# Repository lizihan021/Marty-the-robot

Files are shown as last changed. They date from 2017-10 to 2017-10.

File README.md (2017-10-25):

---
title: DIY Marty the Robot
tags: 
- RaspberryPi
author: Li Zihan 
---

**Abstract**
---

**Marty the Robot** is a robot designed and manufactured by myself. To be honest I made the robot for fun. However, the robot could be used for teaching children programing. 

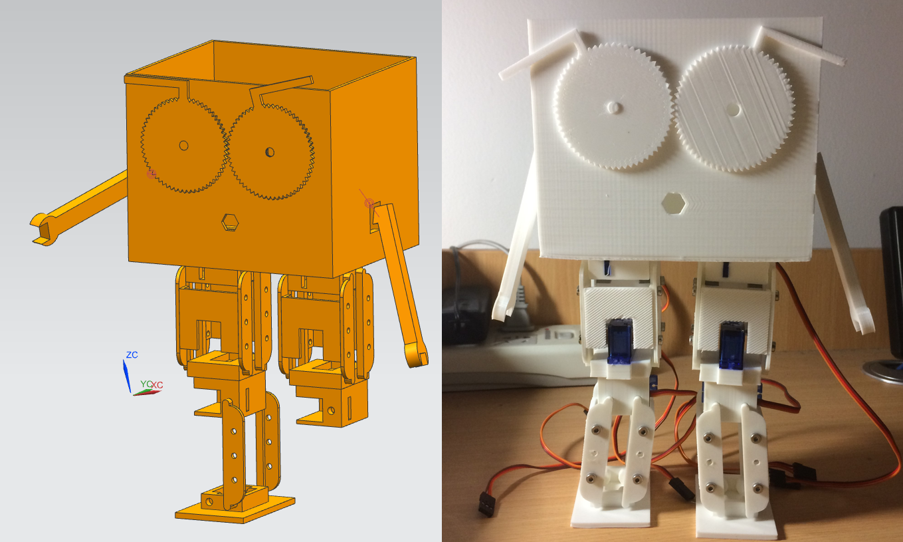
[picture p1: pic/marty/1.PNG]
marty


I used [Siemens NX](https://en.wikipedia.org/wiki/Siemens_NX) for CAD and 3D printed all the parts. Control system was based on Raspberry Pi and PCA9685 with I2C protocol. Marty was able to perform face detection with OpenCV and walk towards its owner. High level API was implemented for controlling the robot such as `walk(),dance()` etc. 

<!-- more -->

## **System Implementation**
### **1. Setup**
#### **Hardware:**
* 8mm*M3 screws 
* a 3D printer with plenty of PLA
* SG90 Servo *9
* PCA9685 module
* Raspberry Pi 3 B+
* Pi Camera
* 500 mAh, 11.1 V Li-battery
* voltage reduction module 11.1 V to 6 V

#### **Software:**
1. When you buy a raspberrypi, it's just a bare board without any operating system. Let's assume you have already installed latest Raspbian OS on your raspberrypi and and have succesfully remote control your pi. If you haven't yet finished, please follow the instruction below to **initialize your raspberrypi**:
   http://yesyzq.github.io/2016/01/09/raspberry/
   Make sure that you have network environment for raspberry pi to work properly.

2. In case you are not familiar with **Linux command**:
   http://yesyzq.github.io/2016/01/17/Linux%E5%91%BD%E4%BB%A4%E4%BB%A5%E5%8F%8A%E5%BF%AB%E6%8D%B7%E9%94%AE%E6%95%B4%E7%90%86/
   You may also refer to any other guide online. There are always abundant resources waiting for you to explore on the internet.

### **2. Implementation:**
#### **Hardware:**
I 3D printed all the parts that are needed to build Marty. The parts are designed using UG NX 10.0 and are exported to .stl files. Then those .stl files are used to generate .gcode or .pcode using slicing softwares. 
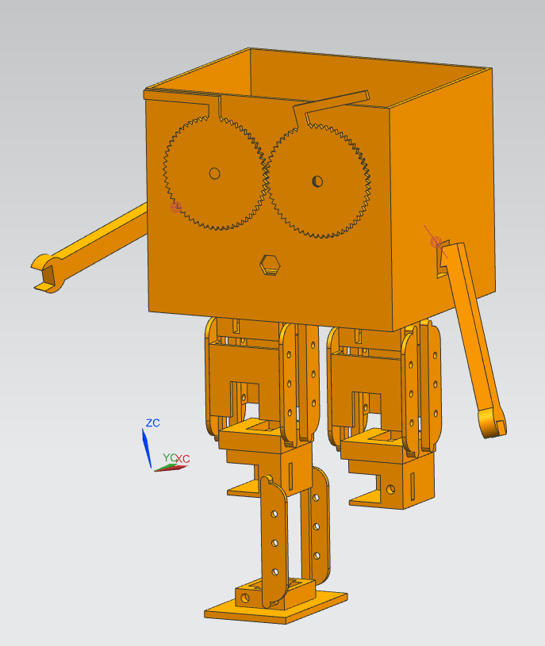
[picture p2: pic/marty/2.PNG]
Assemble the parts in UG

That is what marty is going to look like. (I'm too lazy to assemble another leg ...)
The following are all the files:
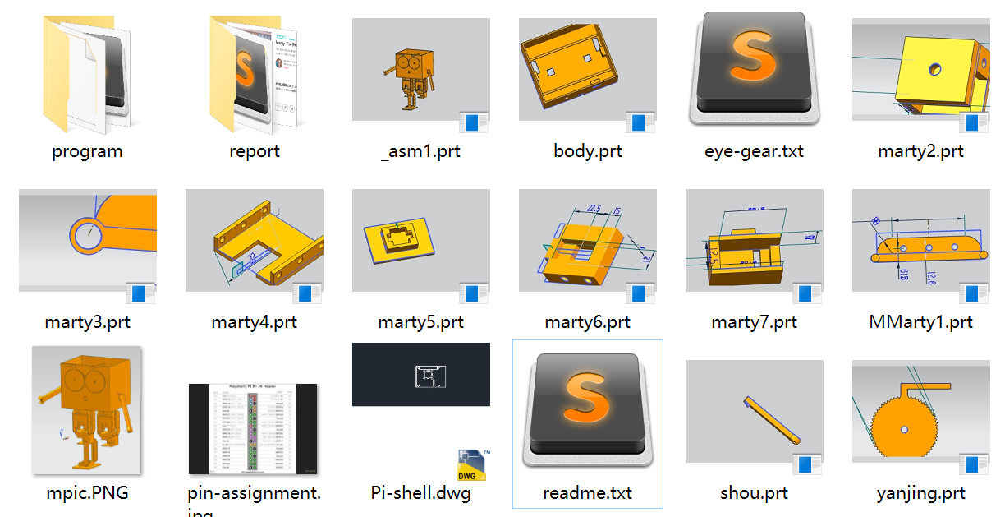
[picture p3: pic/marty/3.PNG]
all the .prt files

You need to export *.prt files to *.stl files for 3D printing.
You need to print:

* 12 pieces of MMarty1.prt - connecting bar
* 8 pieces of marty4.prt ----- supporting plate
* 4 pieces of marty3.prt ----- servo connecting bar
* 2 pieces of marty2.prt ----- third servo
* 2 pieces of marty5.prt ----- feet of marty
* 2 pieces of marty6.prt ----- second servo
* 2 pieces of marty7.prt ----- first servo
* 2 pieces of shou.prt ------- arms of marty
* 2 pieces of yanjing.prt ---- eyes of marty
* 1 piece of body.prt --------- body of marty

Then with the parts, you can assemble marty:
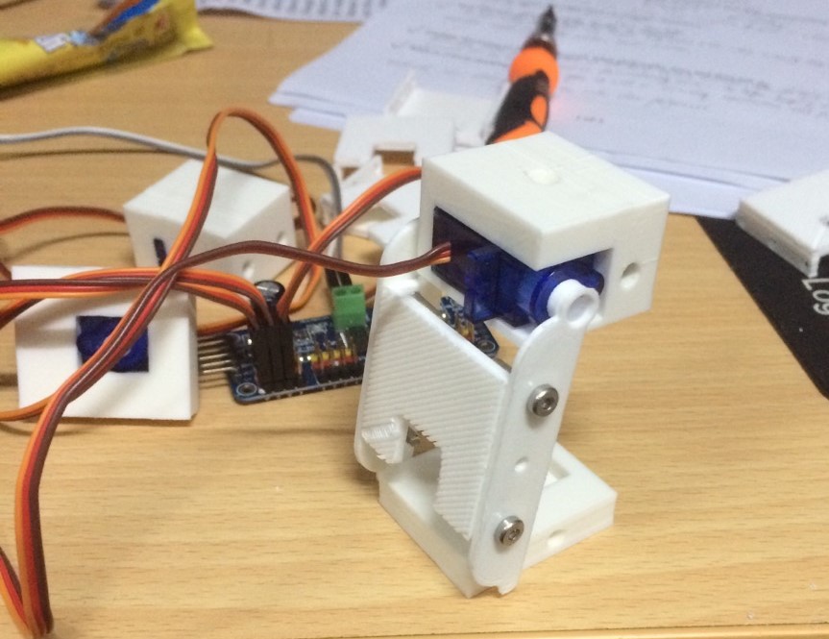
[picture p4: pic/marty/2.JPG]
leg of marty

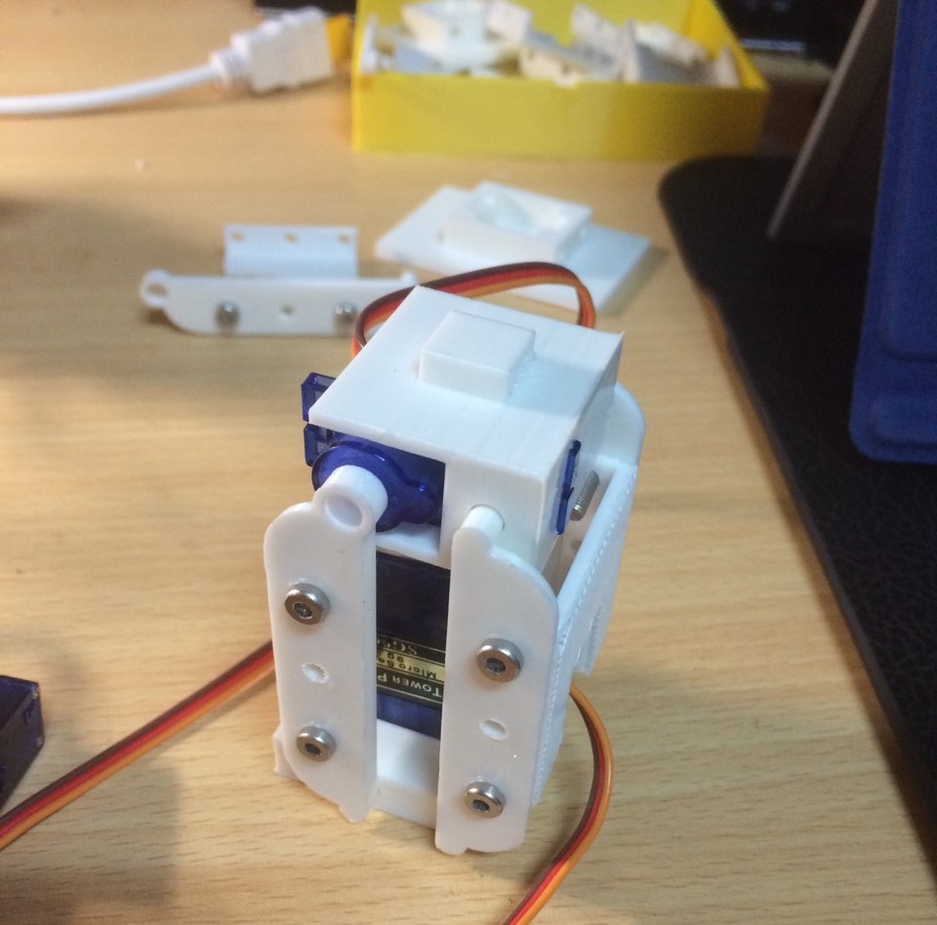
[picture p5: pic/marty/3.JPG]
leg of marty

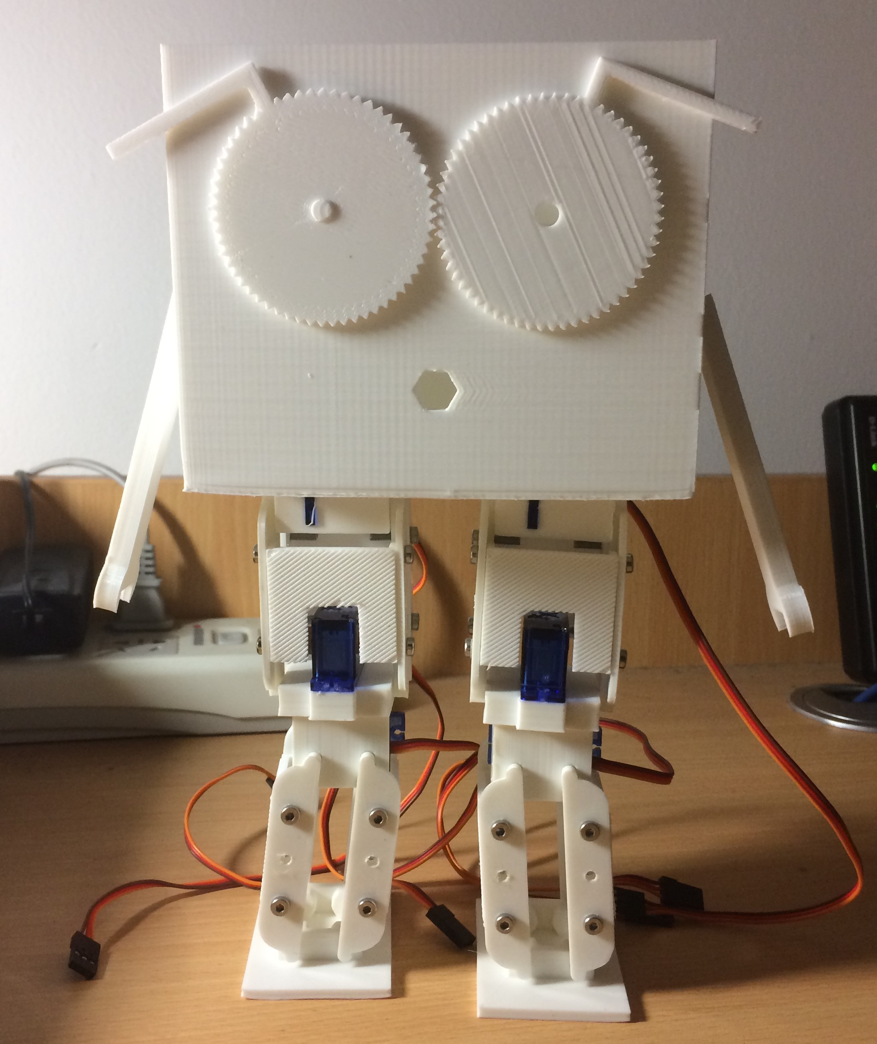
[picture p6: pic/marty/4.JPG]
marty


I also added a speaker on Marty:
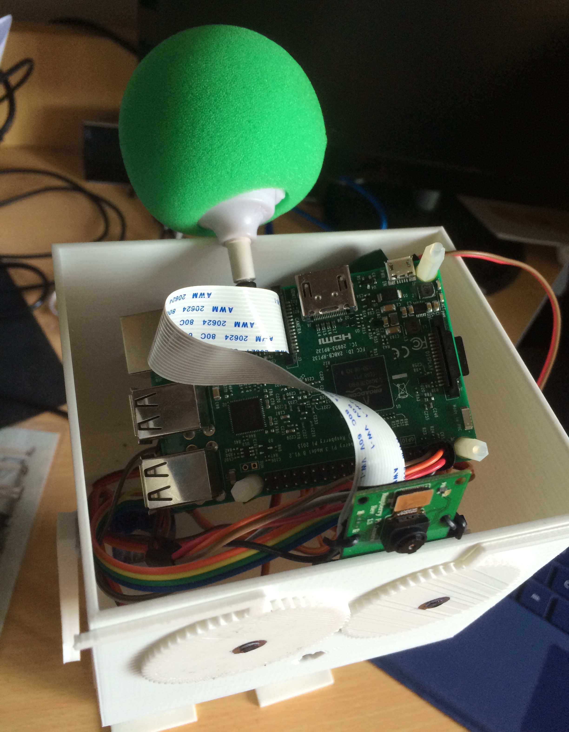
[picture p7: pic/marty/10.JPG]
circuit of marty


#### **Software:**
##### **I. Install OpenCV**
To make Marty capable of face detecting, we install openCV-3.0.0 in Pi 3. The tutorial is mainly based on [this tutorial](http://www.pyimagesearch.com/2015/10/26/how-to-install-opencv-3-on-raspbian-jessie/) Notice you need to run this line of code to solve the depencence problem. `sudo apt-get install build-essential libgtk2.0-dev libjpeg-dev libtiff5-dev libjasper-dev libopenexr-dev cmake python-dev python-numpy python-tk libeigen2-dev yasm libopencore-amrnb-dev libopencore-amrwb-dev libtheora-dev libvorbis-dev libxvidcore-dev libx264-dev libqt4-dev libqt4-opengl-dev sphinx-common texlive-latex-extra libv4l-dev libdc1394-22-dev libavcodec-dev libavformat-dev libswscale-dev libeigen3-dev` 
##### **II. Driver**
To drive Marty, I wrote a library that contains basic instructions to control Marty.
```
Main files: 
	duo.py  # this is the main driven program of marty.
		    # it defines an object called duo which include following functions:
		    # .dance(times, speed) to dance "times" times at "speed" speed
		    # .walk(times, speed)  to walk "times" times at "speed" speed
		    # .turn(angle, speed)  to turn "angle" at "speed" speed
		    # .zhuanyan(times, range, speed) to rotate eyes with range "range"
		    # .dongshou(times, jizhun, range, speed) to move hand at a base angle of 
		    # "jizhun" and range "range"

	face.py # this is the face detection file marty will take picture around every 
			# 0.5 seconds. Pictures is under ./pic folder.
			# If there is face detected, Marty will turn to the direction 
			# of the face. If the face is far from Marty, it will walk toward the 
			# direction of the face.
			# **this file must be run in cv environment**

	boom.py # this file serves as a example if you want to move Marty's hand, eyes
			# and legs simultaniously. DO NOT TRY TO WALK AND DANCE SIMUTANIOUSLY,
			# BECAUSE THAT MIGHT CAUSE ERRORS. 

	PCA9685.py video.py common.py and <files in /xmlf> come from 3rd party.

	other files are test files and serves as examples about how to control Marty.
```
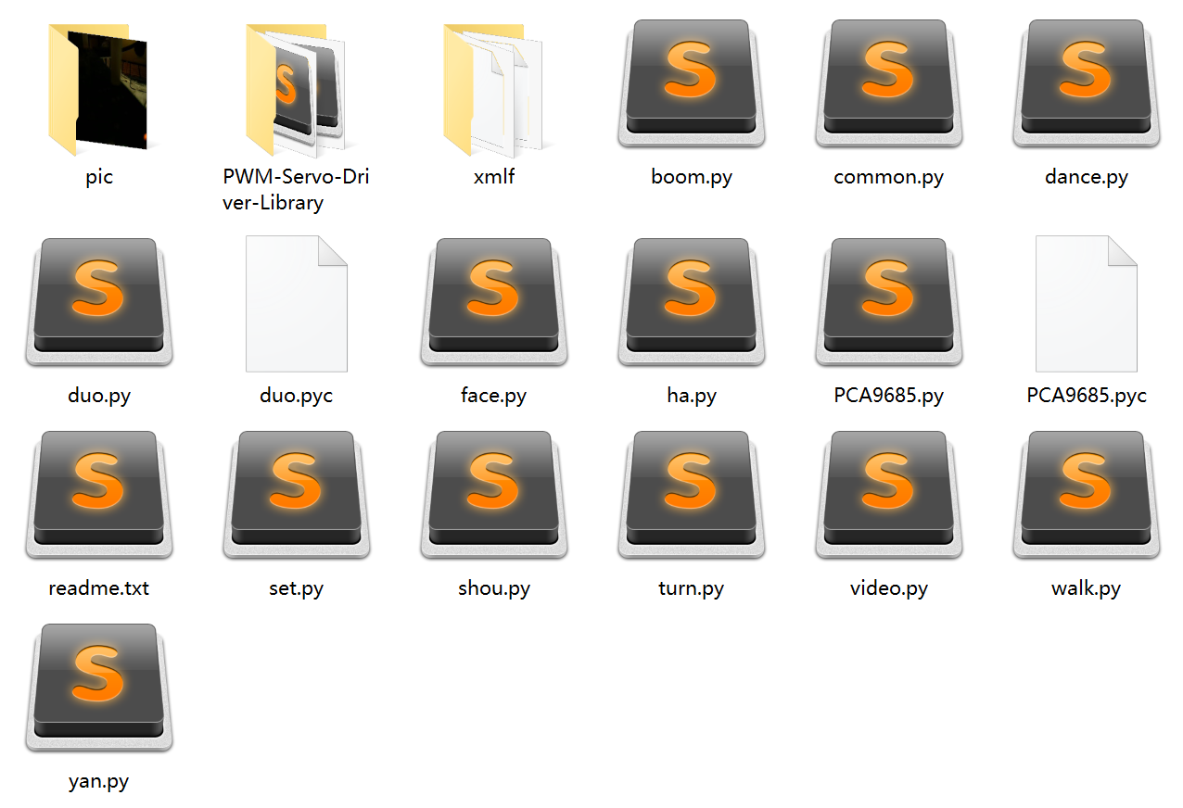
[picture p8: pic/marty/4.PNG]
Driver of Marty


##### **III. Open i2c communication**
Search i2c at `/boot/config.txt` and change the item to 'on'. Then reboot. Check you have open i2c successfully by `sudo i2cdetect -y 1`
### **3. DEMO**
For view demos please visit:

https://lizihan021.github.io/2017/06/18/marty/

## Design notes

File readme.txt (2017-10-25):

this is a project called Marty. 
made by Zihan Li 

FILES:
	*.prt files 		can be open by UG NX 10.0. They are used for 3D printing.
	_asm.prt 			is the assembly file that can give you a direct view of Marty.
	pi-shell.dwg 		is used to hold a fan to cool Raspi down. It is used for acrylic laser cut.
	eye-gear.txt 		is the parameters used to define the gear on Marty's eyes.
	pin-assignment.jpg 	is the GPIO pins on Raspi.

	programs are under /program and there is another Readme file to explain it.

HOW TO BUILD MARTY:
	Material List:
		8mm*M3 screws 
		a 3D printer with plenty of PLA
		SG90 Servo *9
		PCA9685 module
		Raspberry Pi 3 B+
		Pi Camera
		500 mAh, 11.1 V Li-battery
		voltage reduction module 12 V to 6 V

	You need to export *.prt files to *.stl files for 3D printing.
	You need to print:
		12 pieces of MMarty1.prt 	connecting bar
		8 pieces of marty4.prt 		supporting plate
		4 pieces of marty3.prt 		servo connecting bar
		2 pieces of marty2.prt 		third servo
		2 pieces of marty5.prt 		feet of marty
		2 pieces of marty6.prt 		second servo
		2 pieces of marty7.prt 		first servo
		2 pieces of shou.prt 		arms of marty
		2 pieces of yanjing.prt 	eyes of marty
		1 piece of body.prt 		body of marty

HOW TO USE MARTY:
	1. connect i2c ports on Raspi with PCA9685 module
		PIN03 GPIO02 -> SDA
		PIN05 GPIO03 -> SCL
		PIN04 VCC	 -> VCC (NOT "V+" !)
		PIN06 GROUND -> GND

	2. connect voltage reduction module with V+ and GND on the PCA9685 to support power.

	3. run "python set.py" on Raspi and THEN connect the battery to voltage reduction module.

	4. run other programs such as "dance.py" to test Marty. 

Eye gear:
模数 modulus 			0.22
齿数 teeth number 		24
宽度 thickness 			4
压力角 pressure angle 	36

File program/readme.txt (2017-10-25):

# Written by Zihan Li
The program of Marty is written by Python.

The program is based on Raspbian OS on Raspberry Pi 3, with the PREREQUESTS: 
1. the OS has been configed with i2c communication
2. the i2c port is connected with PCA9685 module
3. openCV-3.0.0 is installed in the system

Main files: 
	duo.py  # this is the main driven program of marty.
		    # it defines an object called duo which include following functions:
		    # .dance(times, speed) to dance "times" times at "speed" speed
		    # .walk(times, speed)  to walk "times" times at "speed" speed
		    # .turn(angle, speed)  to turn "angle" at "speed" speed
		    # .zhuanyan(times, range, speed) to rotate eyes
		    # .dongshou(times, jizhun, tange, speed) to move hand

	face.py # this is the face detection file marty will take picture around every 
			# 0.5 seconds. Pictures is under /pic folder.
			# If there is face detected, Marty will turn to the direction 
			# of the face. If the face is far from Marty, it will walk toward the 
			# direction of the face.

	boom.py # this file serves as a example if you want to move Marty's hand, eyes
			# and legs simultaniously. DO NOT TRY TO WALK AND DANCE SIMUTANIOUSLY,
			# BECAUSE THAT MIGHT CAUSE ERRORS. 

	PCA9685.py video.py common.py and <files in /xmlf> come from 3rd party.

	other files are test files and serves as examples about how to control Marty.

File dependency:
	duo.py -> PCA9685.py
	face.py -> video.py
			-> common.py
			-> <files in /xmlf>
			-> </pic>
	boom.py -> yan.py
			-> shou.py
			-> dance.py

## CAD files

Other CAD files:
parts/Pi-shell.dwg
parts/MMarty1.prt
parts/_asm1.prt
parts/body.prt
parts/marty2.prt
parts/marty3.prt
parts/marty4.prt
parts/marty5.prt
parts/marty6.prt
parts/marty7.prt
parts/shou.prt
parts/yanjing.prt

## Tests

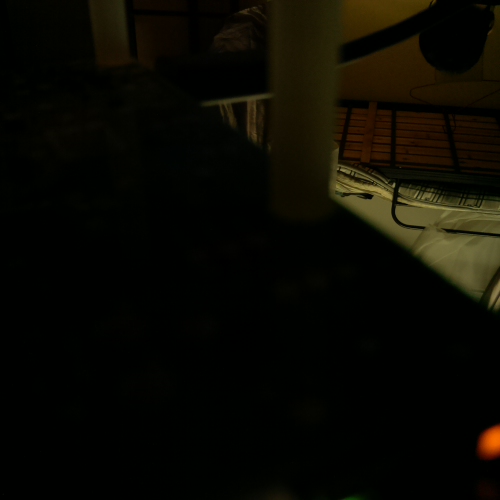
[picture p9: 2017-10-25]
program/pic/test.jpg

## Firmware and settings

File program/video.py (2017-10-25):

#!/usr/bin/env python

'''
Video capture sample.

Sample shows how VideoCapture class can be used to acquire video
frames from a camera of a movie file. Also the sample provides
an example of procedural video generation by an object, mimicking
the VideoCapture interface (see Chess class).

'create_capture' is a convinience function for capture creation,
falling back to procedural video in case of error.

Usage:
    video.py [--shotdir <shot path>] [source0] [source1] ...'

    sourceN is an
     - integer number for camera capture
     - name of video file
     - synth:<params> for procedural video

Synth examples:
    synth:bg=../data/lena.jpg:noise=0.1
    synth:class=chess:bg=../data/lena.jpg:noise=0.1:size=640x480

Keys:
    ESC    - exit
    SPACE  - save current frame to <shot path> directory

'''

import numpy as np
from numpy import pi, sin, cos

import cv2

# built-in modules
from time import clock

# local modules
import common

class VideoSynthBase(object):
    def __init__(self, size=None, noise=0.0, bg = None, **params):
        self.bg = None
        self.frame_size = (640, 480)
        if bg is not None:
            self.bg = cv2.imread(bg, 1)
            h, w = self.bg.shape[:2]
            self.frame_size = (w, h)

        if size is not None:
            w, h = map(int, size.split('x'))
            self.frame_size = (w, h)
            self.bg = cv2.resize(self.bg, self.frame_size)

        self.noise = float(noise)

    def render(self, dst):
        pass

    def read(self, dst=None):
        w, h = self.frame_size

        if self.bg is None:
            buf = np.zeros((h, w, 3), np.uint8)
        else:
            buf = self.bg.copy()

        self.render(buf)

        if self.noise > 0.0:
            noise = np.zeros((h, w, 3), np.int8)
            cv2.randn(noise, np.zeros(3), np.ones(3)*255*self.noise)
            buf = cv2.add(buf, noise, dtype=cv2.CV_8UC3)
        return True, buf

    def isOpened(self):
        return True

class Chess(VideoSynthBase):
    def __init__(self, **kw):
        super(Chess, self).__init__(**kw)

        w, h = self.frame_size

        self.grid_size = sx, sy = 10, 7
        white_quads = []
        black_quads = []
        for i, j in np.ndindex(sy, sx):
            q = [[j, i, 0], [j+1, i, 0], [j+1, i+1, 0], [j, i+1, 0]]
            [white_quads, black_quads][(i + j) % 2].append(q)
        self.white_quads = np.float32(white_quads)
        self.black_quads = np.float32(black_quads)

        fx = 0.9
        self.K = np.float64([[fx*w, 0, 0.5*(w-1)],
                        [0, fx*w, 0.5*(h-1)],
                        [0.0,0.0,      1.0]])

        self.dist_coef = np.float64([-0.2, 0.1, 0, 0])
        self.t = 0

    def draw_quads(self, img, quads, color = (0, 255, 0)):
        img_quads = cv2.projectPoints(quads.reshape(-1, 3), self.rvec, self.tvec, self.K, self.dist_coef) [0]
        img_quads.shape = quads.shape[:2] + (2,)
        for q in img_quads:
            cv2.fillConvexPoly(img, np.int32(q*4), color, cv2.LINE_AA, shift=2)

    def render(self, dst):
        t = self.t
        self.t += 1.0/30.0

        sx, sy = self.grid_size
        center = np.array([0.5*sx, 0.5*sy, 0.0])
        phi = pi/3 + sin(t*3)*pi/8
        c, s = cos(phi), sin(phi)
        ofs = np.array([sin(1.2*t), cos(1.8*t), 0]) * sx * 0.2
        eye_pos = center + np.array([cos(t)*c, sin(t)*c, s]) * 15.0 + ofs
        target_pos = center + ofs

        R, self.tvec = common.lookat(eye_pos, target_pos)
        self.rvec = common.mtx2rvec(R)

        self.draw_quads(dst, self.white_quads, (245, 245, 245))
        self.draw_quads(dst, self.black_quads, (10, 10, 10))


classes = dict(chess=Chess)

presets = dict(
    empty = 'synth:',
    lena = 'synth:bg=../data/lena.jpg:noise=0.1',
    chess = 'synth:class=chess:bg=../data/lena.jpg:noise=0.1:size=640x480'
)


def create_capture(source = 0, fallback = presets['chess']):
    '''source: <int> or '<int>|<filename>|synth [:<param_name>=<value> [:...]]'
    '''
    source = str(source).strip()
    chunks = source.split(':')
    # handle drive letter ('c:', ...)
    if len(chunks) > 1 and len(chunks[0]) == 1 and chunks[0].isalpha():
        chunks[1] = chunks[0] + ':' + chunks[1]
        del chunks[0]

    source = chunks[0]
    try: source = int(source)
    except ValueError: pass
    params = dict( s.split('=') for s in chunks[1:] )

    cap = None
    if source == 'synth':
        Class = classes.get(params.get('class', None), VideoSynthBase)
        try: cap = Class(**params)
        except: pass
    else:
        cap = cv2.VideoCapture(source)
        if 'size' in params:
            w, h = map(int, params['size'].split('x'))
            cap.set(cv2.CAP_PROP_FRAME_WIDTH, w)
            cap.set(cv2.CAP_PROP_FRAME_HEIGHT, h)
    if cap is None or not cap.isOpened():
        #print 'Warning: unable to open video source: ', source
        if fallback is not None:
            return create_capture(fallback, None)
    return cap

if __name__ == '__main__':
    import sys
    import getopt

    print __doc__

    args, sources = getopt.getopt(sys.argv[1:], '', 'shotdir=')
    args = dict(args)
    shotdir = args.get('--shotdir', '.')
    if len(sources) == 0:
        sources = [ 0 ]

    caps = map(create_capture, sources)
    shot_idx = 0
    while True:
        imgs = []
        for i, cap in enumerate(caps):
            ret, img = cap.read()
            imgs.append(img)
            cv2.imshow('capture %d' % i, img)
        ch = 0xFF & cv2.waitKey(1)
        if ch == 27:
            break
        if ch == ord(' '):
            for i, img in enumerate(imgs):
                fn = '%s/shot_%d_%03d.bmp' % (shotdir, i, shot_idx)
                cv2.imwrite(fn, img)
                print fn, 'saved'
            shot_idx += 1
    cv2.destroyAllWindows()

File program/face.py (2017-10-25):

#!/usr/bin/env python

import numpy as np
import cv2
import os
import time
# local modules
from video import create_capture
from common import clock, draw_str
from duo import duo

help_message = '''
USAGE: facedetect.py [--cascade <cascade_fn>] [--nested-cascade <cascade_fn>] [<video_source>]
'''

def detect(img, cascade):
    rects = cascade.detectMultiScale(img, scaleFactor=1.3, minNeighbors=4, minSize=(30, 30), flags = cv2.CASCADE_SCALE_IMAGE)
    if len(rects) == 0:
        return []
    rects[:,2:] += rects[:,:2]
    return rects

def draw_rects(img, rects, color):
    for x1, y1, x2, y2 in rects:
        cv2.rectangle(img, (x1, y1), (x2, y2), color, 2)

if __name__ == '__main__':
    import sys, getopt
    print help_message

    marty = duo()
    marty.init()

    args, video_src = getopt.getopt(sys.argv[1:], '', ['cascade=', 'nested-cascade='])
    try:
        video_src = video_src[0]
    except:
        video_src = 0
    args = dict(args)
    #define the xml files used to detect the face in the picture
    cascade_fn = args.get('--cascade', "xmlf/haarcascade_frontalface_alt.xml")
    nested_fn  = args.get('--nested-cascade', "xmlf/haarcascade_eye.xml")

    cascade = cv2.CascadeClassifier(cascade_fn)
    nested = cv2.CascadeClassifier(nested_fn)

    cam = create_capture(video_src, fallback='synth:bg=pic/test.jpg')

    while True:
        #take a picture
        os.system('raspistill -o pic/test.jpg -t 40 -w 500 -h 500 -q 50')
        time.sleep(0.01)
        cam = create_capture(video_src, fallback='synth:bg=pic/test.jpg')
        ret, img = cam.read()
        gray = cv2.cvtColor(img, cv2.COLOR_BGR2GRAY)
        gray = cv2.equalizeHist(gray)

        t = clock()
        rects = detect(gray, cascade)
        vis = img.copy()
        draw_rects(vis, rects, (0, 255, 0))
        if len(rects):
            for x1, y1, x2, y2 in rects:
                xmid = (x2 + x1)/2
                kuan = (x2 - x1)
                if (xmid>300 and xmid<495):
                    marty.turn((250-xmid)*40/250,5)
                if (xmid>5 and xmid<200):
                    marty.turn((250 -xmid)*40/250,5)
                if (kuan>5 and kuan<150):
                    marty.walk(2,7) 
                '''
                roi = gray[y1:y2, x1:x2]
                vis_roi = vis[y1:y2, x1:x2]
                subrects = detect(roi.copy(), nested)
                draw_rects(vis_roi, subrects, (255, 0, 0))
                '''
        dt = clock() - t

        draw_str(vis, (20, 20), 'time: %.1f ms' % (dt*1000))
        #cv2.imshow('facedetect', vis)
        print rects

        if 0xFF & cv2.waitKey(5) == 27:
            break
        #if KeyboardInterrupt:
        #    break
            
    cv2.destroyAllWindows()
